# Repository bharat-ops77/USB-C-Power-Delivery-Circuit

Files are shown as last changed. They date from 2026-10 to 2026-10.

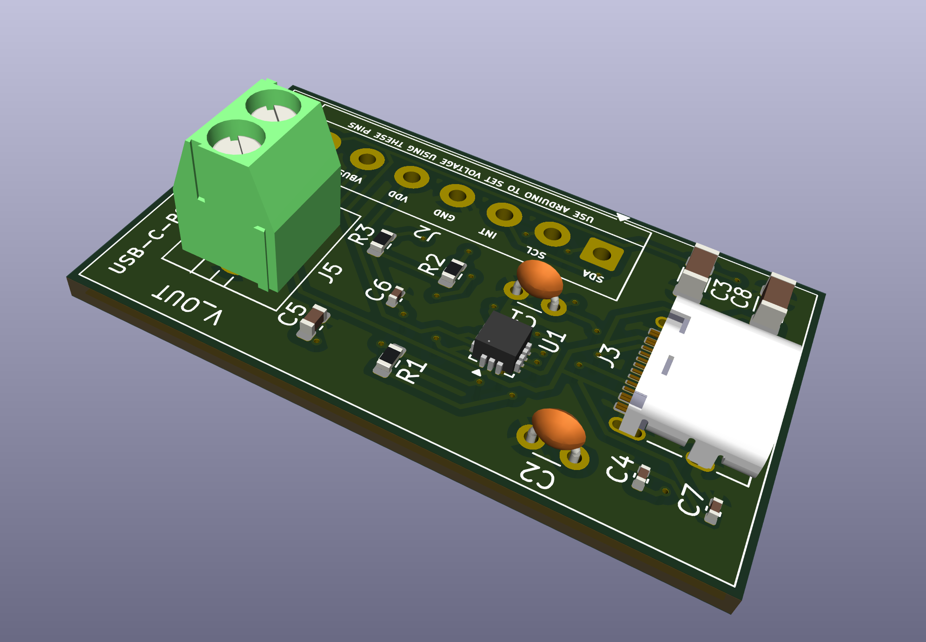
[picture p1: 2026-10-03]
Docs/Images/3D-model.png

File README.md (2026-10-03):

#  • USB-C-Power-Delivery-Circuit
A custom hardware and firmware solution for negotiating Power Delivery (PD) contracts from USB-C sources. This project utilizes an Arduino-compatible microcontroller alongside the FUSB302B USB Type-C controller to request specific voltage and current profiles from a compatible USB-C charger.

# • Repository Structure

```
usb-c-pd-trigger/
├── Firmware/
│   ├── usb-c-demo.ino             # Main Arduino sketch
│   ├── FUSB302.c / FUSB302.h      # FUSB302B chip driver
│   ├── tcpm_driver.cpp / .h       # Hardware I2C wrapper
│   ├── usb_pd_policy.c            # USB PD policy engine
│   ├── usb_pd_protocol.c          # USB PD state machine
│   ├── usb_pd_driver.c / .h       # Sink capabilities and board definitions
│   ├── usb_pd.h                   # Core PD protocol definitions
│   └── usb_pd_tcpm.h              # Type-C Port Manager interface
├── Hardware/
│   ├── Schematics/                # PDF schematics of the trigger board
│   ├── Gerbers/                   # ZIP file containing Gerber files for PCB fabrication
│   └── Source/                    # KiCad project files
├── Docs/
│   ├── images/                    # High-resolution photos of the populated board
│   └── datasheets/                #  FUSB
├── LICENSE                        # GNU License
└── README.md                      # Project documentation (Template below)
```

##  • Features 
###  • FUSB302B TCPC Integration: 
 • Full Type-C Port Controller implementation over I2C.   
 • Dynamic Voltage Switching: Cycle through available Power Data Objects (PDOs) offered by the charger using a physical pushbutton.  
 • Status Indicators: Onboard LED provides visual feedback for state changes and debugging.  
 • Customizable Sink Capabilities: Default sink profiles request 5V, 9V, and 20V at 500mA, with the driver supporting configurations up to 60W (12V       max operating, 5A peak). 
##  • Schematic 


# • Hardware Specifications
## Pin Mapping
### The firmware expects the following pin connections to the microcontroller:
Gemini_Generated_Image_mlpsymlpsymlpsym

## • System Limits
The safety boundaries defined in the firmware (usb_pd_driver.h) are:
Maximum Power: 60 W   
Maximum Current: 5 A   
Maximum Voltage: 12 V

## • Firmware Architecture
The firmware acts as a USB-C PD Sink (UFP). It is divided into three primary layers:   
### • TCPM (Type-C Port Manager):
Handles the I2C communication with the FUSB302B, pushing physical layer resets, managing the RX/TX FIFOs, and measuring CC pin states.   
### • PD Protocol Layer:
A state machine (usb_pd_protocol.c) that handles message transmission, GoodCRC acknowledgments, Hard/Soft resets, and contract negotiations.
### • PD Policy Engine: 
Determines which voltages to accept and request based on the capabilities advertised by the source charger (usb_pd_policy.c)

## • Getting Started
### • Prerequisites
 1. Arduino IDE (or PlatformIO).
 2. An ESP8266, ESP32, or similar Arduino-compatible board containing D3, D4, and D5 pins.
 ### • Installation & Flashing
 1. Clone this repository to your local machine.
 2. Open Firmware/usb-c-pd-trigger.ino in your Arduino IDE.   
 3. Ensure the Wire library is available for your target board.
 4. Compile and upload the firmware to your microcontroller.

 ## • Usage
 1. Connect the board to a USB-C PD power supply.
 2. The state machine will initialize in PD_STATE_SNK_DISCONNECTED and automatically negotiate the first available voltage contract (usually 5V).     3. Press the pushbutton (D4): The trigger board will initiate a soft reset. Upon recovering the connection, it steps to the next available source   capability index.   
 4. Observe the LED (D5): The LED state toggles on each successful button press to confirm the interaction.
 ## • Connection Diagram
 sch

## • Designed PCB
<table>
  <tr>
    <th>First Layer</th>
    <th>Second Layer</th>
  </tr>
  <tr>
    <td>
</td>
    <td>
</td>
  </tr>
</table>

## • Rendered PCB (Without Components)
<table>
  <tr>
    <th>First Layer</th>
    <th>Second Layer</th>
  </tr>
  <tr>
    <td>
  </td>
    <td>

</td>
  </tr>
</table>

## • 3D Model (With Components)


#### • Feel absolutely free to suggest better architecture or board layouts , download or fabricate the PCB and create your own project files using this repo.

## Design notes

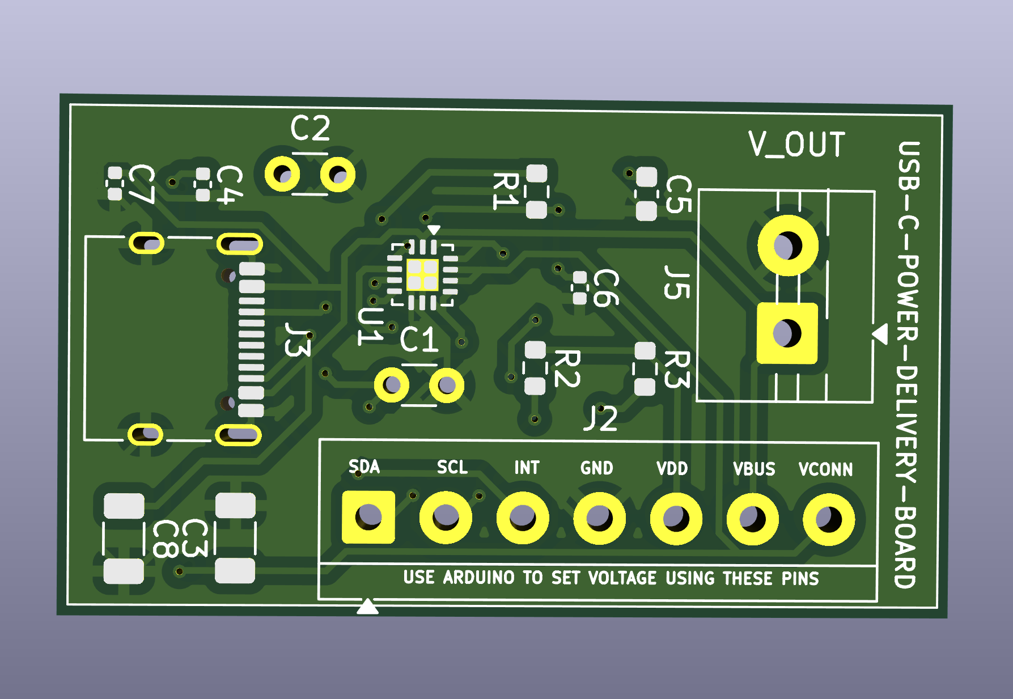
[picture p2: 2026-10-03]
Docs/Images/PCB_front.png

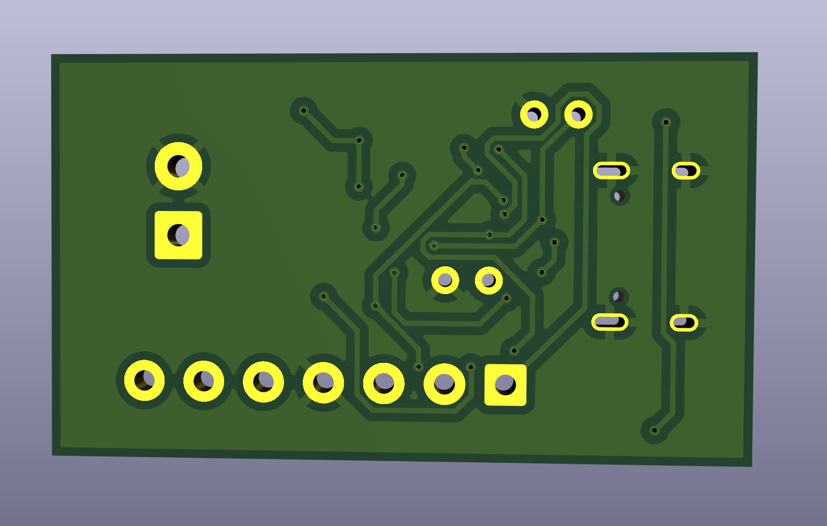
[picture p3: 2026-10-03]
Docs/Images/PCB_back.png

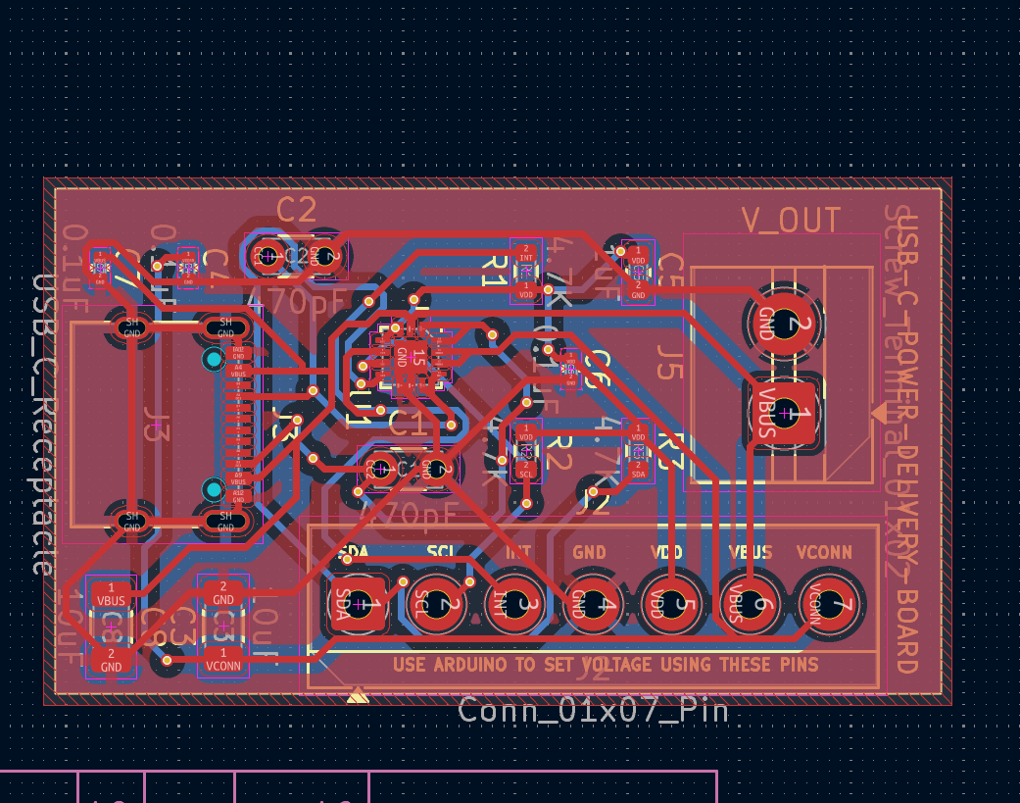
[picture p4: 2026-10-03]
Docs/Images/First PCB Layer.png

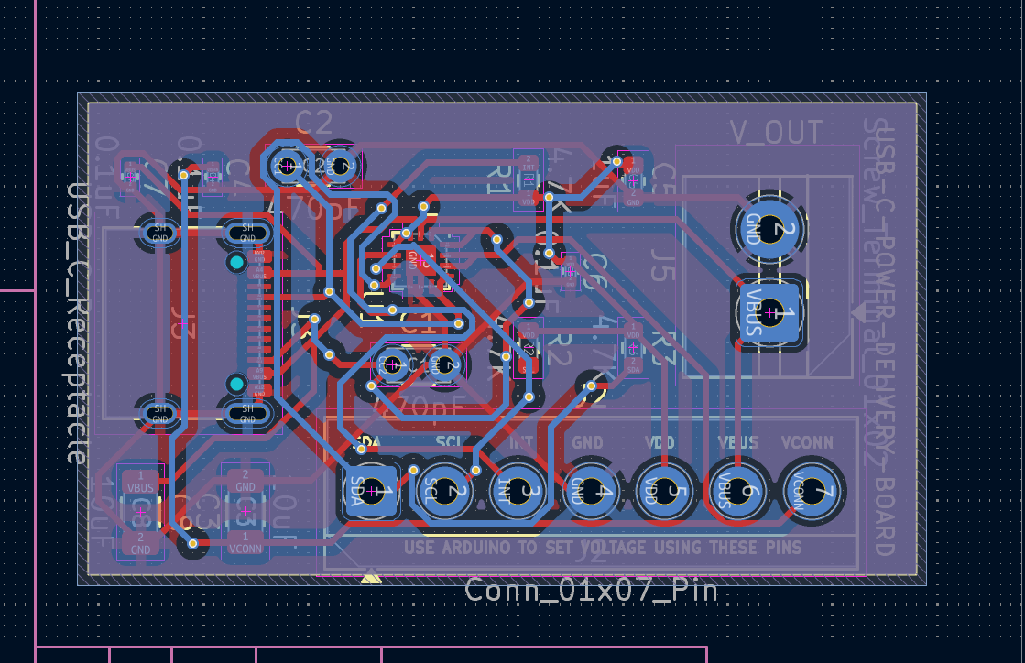
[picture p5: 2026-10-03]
Docs/Images/Second PCB Layer.png

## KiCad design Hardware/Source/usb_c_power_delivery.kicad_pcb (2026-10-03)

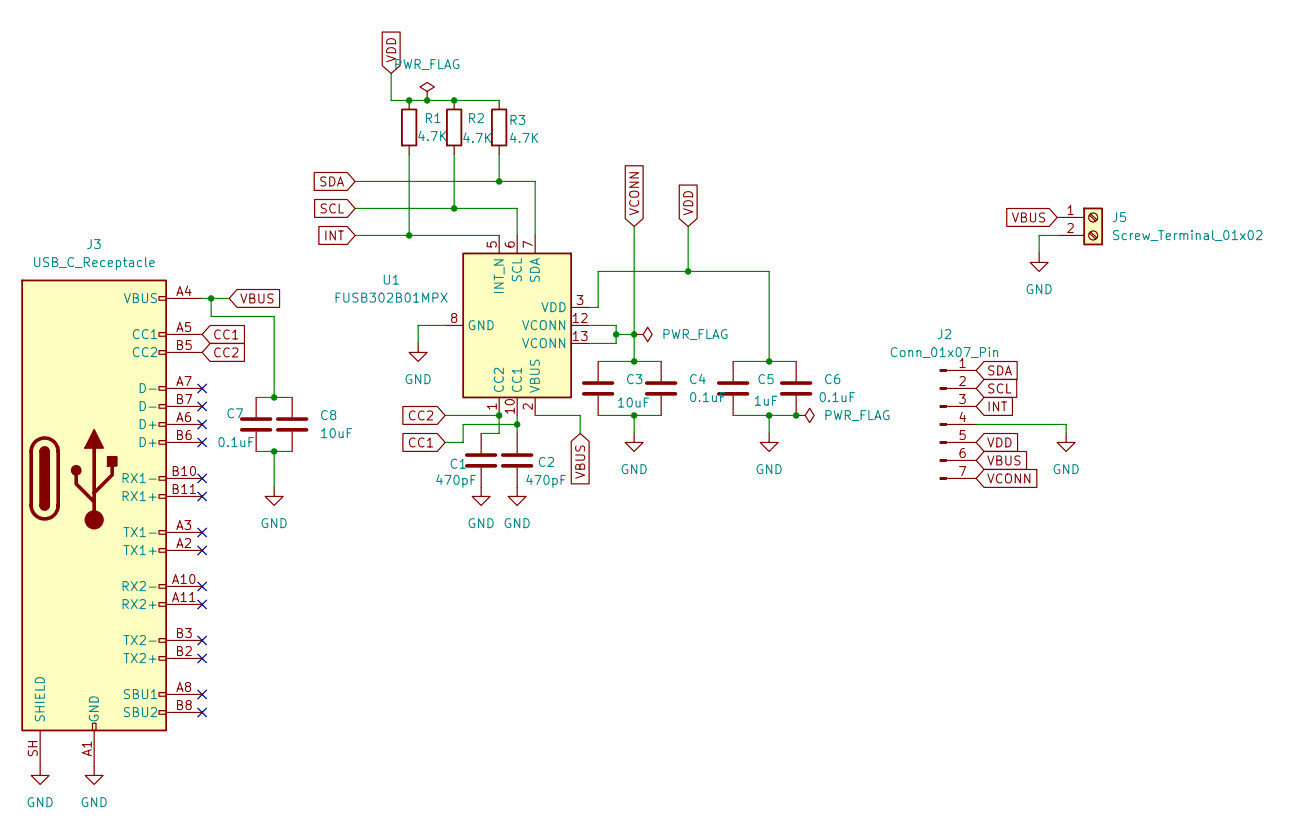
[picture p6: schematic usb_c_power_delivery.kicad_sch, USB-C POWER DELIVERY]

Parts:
C1, C2: 470pF; C_Disc_D3.0mm_W1.6mm_P2.50mm
C3, C8: 10uF; C_1206_3216Metric
C4, C6, C7: 0.1uF; C_0402_1005Metric
C5: 1uF; C_0603_1608Metric
J2: Conn_01x07_Pin; TerminalBlock_4Ucon_1x07_P3.50mm_Horizontal
J3: USB_C_Receptacle; USB_C_Receptacle_XKB_U262-16XN-4BVC11
J5: Screw_Terminal_01x02; TerminalBlock_MaiXu_MX126-5.0-02P_1x02_P5.00mm
R1, R2, R3: 4.7K; R_0603_1608Metric
U1: FUSB302B01MPX; WQFN-14-1EP_2.5x2.5mm_P0.5mm_EP1.45x1.45mm

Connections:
CC1: C2.1, J3.A5 (CC1), U1.10 (CC1), U1.11 (CC1)
CC2: C1.1, J3.B5 (CC2), U1.1 (CC2), U1.14 (CC2)
GND: C1.2, C2.2, C3.2, C4.2, C5.2, C6.2, C7.2, C8.2, J2.4, J3.A1 (GND), J3.A12 (GND), J3.B1 (GND), J3.B12 (GND), J3.SH (SHIELD), J5.2, U1.8 (GND), U1.9 (GND), U1.15 (GND)
INT: J2.3, R1.2, U1.5 (INT_N)
SCL: J2.2, R2.2, U1.6 (SCL)
SDA: J2.1, R3.2, U1.7 (SDA)
VBUS: C7.1, C8.1, J2.6, J3.A4 (VBUS), J3.A9 (VBUS), J3.B4 (VBUS), J3.B9 (VBUS), J5.1, U1.2 (VBUS)
VCONN: C3.1, C4.1, J2.7, U1.12 (VCONN), U1.13 (VCONN)
VDD: C5.1, C6.1, J2.5, R1.1, R2.1, R3.1, U1.3 (VDD), U1.4 (VDD)

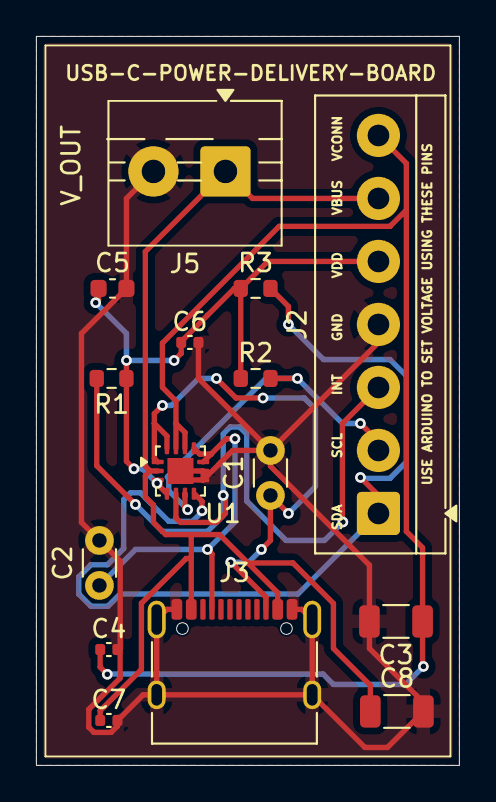
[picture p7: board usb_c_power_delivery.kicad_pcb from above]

Board: 2 copper layers, 23.5 x 40.5 mm, 15 parts (0 on the bottom side), 9 nets.

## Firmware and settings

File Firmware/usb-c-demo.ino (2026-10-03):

#include <Wire.h>
#include "tcpm_driver.h"
#include "usb_pd.h"

const int usb_pd_int_pin = D3;
const int debug_led_pin  = D5;
const int pushbutton_pin = D4;
int pushbutton_last_state, pushbutton_current_state, pushbutton_last_time, pushbutton_current_time;
int debug_led_current_state = 0;
int pd_source_cap_current_index = 0, pd_source_cap_max_index = 0;

// USB-C Specific - TCPM start 1
const struct tcpc_config_t tcpc_config[CONFIG_USB_PD_PORT_COUNT] = {
  {0, fusb302_I2C_SLAVE_ADDR, &fusb302_tcpm_drv},
};
// USB-C Specific - TCPM end 1

void setup() {
  pinMode(usb_pd_int_pin, INPUT);
  pinMode(debug_led_pin, OUTPUT);
  pinMode(pushbutton_pin, INPUT_PULLUP);
  pushbutton_last_state = 1;
  pushbutton_last_time = 0;
  digitalWrite(debug_led_pin, LOW);
  
  Wire.begin();
  Wire.setClock(400000);
  
  tcpm_init(0);
  delay(50);
  pd_init(0);
  delay(50);
}

void loop() {
  int reset = 0;
  pushbutton_current_state = digitalRead(pushbutton_pin);
  pushbutton_current_time = millis();
  if ((pushbutton_current_state == 0) && (pushbutton_last_state == 1) && ((pushbutton_current_time - pushbutton_last_time) < 100)) {
    if (debug_led_current_state) {
      digitalWrite(debug_led_pin, LOW);
      debug_led_current_state = 0;
    } else {
      digitalWrite(debug_led_pin, HIGH);
      debug_led_current_state = 1;
    }
    if (pd_source_cap_current_index < pd_source_cap_max_index) {
      pd_source_cap_current_index++;
    } else {
      pd_source_cap_current_index = 0;
    }
    //pd[0].task_state = PD_STATE_SOFT_RESET);
    reset = 1;
  }
  pushbutton_last_state = pushbutton_current_state;
  pushbutton_last_time = pushbutton_current_time;

  
  if (LOW == digitalRead(usb_pd_int_pin)) {
      tcpc_alert(0);
  }
  
  pd_run_state_machine(0, reset);
  // For some reason, a delay of 4 ms seems to be best
  // My guess is that spamming the I2C bus too fast causes problems
  delay(4);
}

void pd_process_source_cap_callback(int port, int cnt, uint32_t *src_caps)
{
  //digitalWrite(debug_led_pin, HIGH);
  pd_source_cap_max_index = cnt - 1;
}
